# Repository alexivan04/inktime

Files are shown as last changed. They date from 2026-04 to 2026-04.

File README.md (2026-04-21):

# InkTime – Open Source Smartwatch Hardware Project

## Overview
InkTime is an open-source, low-cost smartwatch hardware platform designed for mass production.  
This repository contains the complete hardware, manufacturing, and mechanical design files for the device.

The project includes:
- electronic schematic and PCB layout
- manufacturing outputs (Gerber, BOM, Pick & Place)
- complete 3D mechanical assembly
- documentation and design decisions
- validation and review updates

## Repository Structure

```text
InkTime/
│
├── Hardware/
│   ├── inktime.sch
│   ├── inktime.brd
│   └── schematic.pdf
│
├── Manufacturing/
│   ├── gerbers.zip
│   ├── bom.csv
│   └── pick_and_place.csv
│
├── Mechanical/
│   ├── inktime_assembly.step
│   └── inktime_assembly.f3d
│
├── Images/
│   ├── pcb_top.png
│   ├── pcb_bottom.png
│   ├── render_front.png
│   └── exploded_view.png
│
├── LICENSE
└── README.md
````

---

## Block Diagram

```text
Battery
   │
   ▼
Power Management (charger + regulation)
   │
   ▼
nRF52840 Microcontroller
   ├── IMU Sensor (I2C / SPI)
   ├── E-paper Display (SPI)
   ├── Buttons (GPIO)
   ├── USB-C Interface
   ├── Vibration Motor / Shaker
   └── Debug / Test Pads
```

---

## Hardware Architecture

The smartwatch is built around the **nRF52840** microcontroller, selected for:

* low power consumption
* integrated BLE support
* sufficient GPIO availability
* embedded ARM Cortex-M4 core

### Main Modules

* **Microcontroller:** nRF52840
* **Display:** e-paper display connected via SPI
* **Motion Sensor:** IMU connected via I2C/SPI
* **Power Supply:** Li-Po battery with charging IC and voltage regulation
* **User Input:** 3 push buttons
* **Feedback:** vibration motor (shaker)
* **Communication:** USB-C + BLE
* **Programming/Test:** dedicated test pads

---

## PCB Design Notes

### Stack-up

* **4-layer PCB**
* components placed **TOP layer only**
* routing on both TOP and BOTTOM
* GND planes on 1 and 3 layers

### Routing Rules

* power traces: **0.30 mm**
* signal traces: **minimum 0.15 mm**
* no right-angle routing
* minimized vias on power lines
* decoupling capacitors placed near IC supply pins

### RF Requirements

* antenna positioned at PCB edge
* no copper under antenna
* no signal traces below antenna
* board cutout included below antenna region

---

## Mechanical Integration

The PCB is designed to fit inside the provided smartwatch enclosure.

## Design Decisions / Notes

* accepted minor dimension warnings for button and USB alignment per project instructions
* battery connected directly to test pads to save internal volume
* all decoupling capacitors placed as close as possible to supply pins
* RF section isolated with stitched ground vias

---

## License

This project is released under the **Apache 2.0 License**.

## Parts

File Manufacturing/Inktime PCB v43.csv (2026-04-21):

Qty | Value | Device | Package | Parts | Description | ARROW_PART_NUMBER | ARROW_PRICE-STOCK | AVAILABILITY | CHECK_PRICES | COPYRIGHT | DESCRIPTION | DIGI-KEY_PART_NUMBER_1 | DIGI-KEY_PART_NUMBER_2 | DIGI-KEY_PART_NUMBER_3 | HEIGHT | JLCPCB | MANUFACTURER_NAME | MANUFACTURER_PART_NUMBER | MF | MFR_NAME | MOUSER_PART_NUMBER | MOUSER_PRICE-STOCK | MP | PACKAGE | POPULARITY | PRICE | PROD_ID | PURCHASE-URL | SNAPEDA_LINK | SPICEMODEL | SPICEPREFIX | TP_SIGNAL_NAME | VALUE
1 |  | ESP32_C6_LIBRARY_7_JUMPER_SJ | ESP32_C6_LIBRARY_7_JUMPER_SJ | SJ1 | SMD solder JUMPER |  |  |  |  |  |  |  |  |  |  |  |  |  |  |  |  |  |  |  | 3
1 |  | NORDIC_NRF_2_INDUCTOR_0402_L | NORDIC_NRF_2_RESC0402_L | U$5 | Generic chip inductor
3 | 0 | ERA-1AEB3401C_CPF0201D7K68C1 | ERA-1AEB3401C_0201 | R6, R7, R15 | 7.68k 0201 Thin Film Surface Mount Fixed Resistor +/-0.5% 0.031W CPF0201D7K68C1
6 | 0.1u | GRM011R60J152KE01L_2_GRM011R60J152KE01L | GRM011R60J152KE01L_2_CAPC0201X13N | C4, C5, C7, C8, C9, C37 | Check availability |  |  | In Stock | https://www.snapeda.com/parts/GRM011R60J152KE01L/Murata/view-part/?ref=eda |  | SMD Capacitor X5R(EIA) with Capacitance: 1500pF Tol. 10%. Rated Voltage: 6.3Vdc |  |  |  |  |  |  |  | Murata |  |  |  | GRM011R60J152KE01L | 0201 Murata |  | None |  |  | https://www.snapeda.com/parts/GRM011R60J152KE01L/Murata/view-part/?ref=snap
1 | 0.1u/50V | NORDIC_NRF_3_CAPACITOR_0201_L | NORDIC_NRF_3_RESC0201_L | C48 | Generic chip capacitor
1 | 0.47 | ERA-1AEB3401C_CPF0201D7K68C1 | ERA-1AEB3401C_0201 | R2 | 7.68k 0201 Thin Film Surface Mount Fixed Resistor +/-0.5% 0.031W CPF0201D7K68C1
1 | 1.0u | ESP32_C6_LIBRARY_1_ESP32_WROVER_EAGLE-LTSPICE_CC0402 | ESP32_C6_LIBRARY_1_ESP32_WROVER_EAGLE-LTSPICE_C0402 | C14 | CAPACITOR, European symbol |  |  |  |  |  |  |  |  |  |  |  |  |  |  |  |  |  |  |  |  |  |  |  |  | NONE | C
5 | 100n | NORDIC_NRF_3_CAPACITOR_0201_L | NORDIC_NRF_3_RESC0201_L | C3, C22, C26, C30, C33 | Generic chip capacitor
1 | 100p | NORDIC_NRF_3_CAPACITOR_0201_L | NORDIC_NRF_3_RESC0201_L | C23 | Generic chip capacitor
5 | 10K | ERA-1AEB3401C_CPF0201D7K68C1 | ERA-1AEB3401C_0201 | R1, R5, R12, R13, R14 | 7.68k 0201 Thin Film Surface Mount Fixed Resistor +/-0.5% 0.031W CPF0201D7K68C1
2 | 10u | ESP32_C6_LIBRARY_1_ESP32_WROVER_EAGLE-LTSPICE_CC0402 | ESP32_C6_LIBRARY_1_ESP32_WROVER_EAGLE-LTSPICE_C0402 | C11, C17 | CAPACITOR, European symbol |  |  |  |  |  |  |  |  |  |  |  |  |  |  |  |  |  |  |  |  |  |  |  |  | NONE | C
1 | 10u | NORDIC_NRF_2_INDUCTOR_0402_L | NORDIC_NRF_2_RESC0402_L | U$8 | Generic chip inductor
2 | 12p | NORDIC_NRF_3_CAPACITOR_0201_L | NORDIC_NRF_3_RESC0201_L | C27, C28 | Generic chip capacitor
1 | 15n | NORDIC_NRF_2_INDUCTOR_0402_L | NORDIC_NRF_2_RESC0402_L | U$4 | Generic chip inductor
4 | 1u | GRM011R60J152KE01L_2_GRM011R60J152KE01L | GRM011R60J152KE01L_2_CAPC0201X13N | C1, C2, C6, C10 | Check availability |  |  | In Stock | https://www.snapeda.com/parts/GRM011R60J152KE01L/Murata/view-part/?ref=eda |  | SMD Capacitor X5R(EIA) with Capacitance: 1500pF Tol. 10%. Rated Voltage: 6.3Vdc |  |  |  |  |  |  |  | Murata |  |  |  | GRM011R60J152KE01L | 0201 Murata |  | None |  |  | https://www.snapeda.com/parts/GRM011R60J152KE01L/Murata/view-part/?ref=snap
10 | 1u/50V | NORDIC_NRF_3_CAPACITOR_0201_L | NORDIC_NRF_3_RESC0201_L | C38, C39, C40, C41, C42, C43, C44, C45, C46, C47 | Generic chip capacitor
2 | 2.2 | ERA-1AEB3401C_CPF0201D7K68C1 | ERA-1AEB3401C_0201 | R3, R4 | 7.68k 0201 Thin Film Surface Mount Fixed Resistor +/-0.5% 0.031W CPF0201D7K68C1
3 | 2025-10-22_07-23-44_LIBRARY_EVP-AKE31ASW_EVP-AKE31A_PAN | 2025-10-22_07-23-44_LIBRARY_EVP-AKE31ASW_EVP-AKE31A_PAN | 2025-10-22_07-23-44_LIBRARY_SW_EVP-AKE31A_PAN | SW1, SW2, SW3 |  |  |  |  |  | Copyright (C) 2025 Ultra Librarian. All rights reserved. |  | P123437TR-ND | P123437CT-ND | P123437DKR-ND |  |  | Panasonic | EVP-AKE31A
1 | 20V/4.2A/52mO/1.4W | ESP32_C6_LIBRARY_4_ESP32_WROVER_SPARKFUN-DISCRETESEMI_MOSFET_PCH-DMG2305UX-7 | ESP32_C6_LIBRARY_4_ESP32_C6_LIBRARY_4_ESP32_C6_LIBRARY_4_ESP32_C6_LIBRARY_4_ESP32_WROVER_SPARKFUN-DISCRETESEMI_SOT23-3 | Q2 | P-channel MOSFETs |  |  |  |  |  |  |  |  |  |  |  |  |  |  |  |  |  |  |  |  |  | TRAN-14388 |  |  |  |  |  | 20V/4.2A/52mO/1.4W
2 | 22u | ESP32_C6_LIBRARY_1_ESP32_WROVER_EAGLE-LTSPICE_CC0402 | ESP32_C6_LIBRARY_1_ESP32_WROVER_EAGLE-LTSPICE_C0402 | C12, C13 | CAPACITOR, European symbol |  |  |  |  |  |  |  |  |  |  |  |  |  |  |  |  |  |  |  |  |  |  |  |  | NONE | C
1 | 2450AT18B100E_2450AT18B100E | 2450AT18B100E_2450AT18B100E | 2450AT18B100E_ANTC3216X140N | ANT1 | Antennas 2.45GHz ANTENNA | 2450AT18B100E | https://www.arrow.com/en/products/2450at18b100e/johanson-dielectrics?utm_currency=USD&region=nac |  |  |  | Antennas 2.45GHz ANTENNA |  |  |  | 1.4mm |  | JOHANSON TECHNOLOGY | 2450AT18B100E |  |  | 609-2450AT18B100E | https://www.mouser.co.uk/ProductDetail/Johanson-Technology/2450AT18B100E?qs=yCnrNFeXz%252Bh5MFsFIXGZGA%3D%3D
1 | 32.768kHz | NORDIC_NRF_1_XTAL_32KHZ | NORDIC_NRF_1_XTAL_3215_N | X1
1 | 32MHz | NORDIC_NRF_XTAL_32MHZ | NORDIC_NRF_BT-XTAL_2016_N | U$22
2 | 3K3 | ERA-1AEB3401C_CPF0201D7K68C1 | ERA-1AEB3401C_0201 | R10, R11 | 7.68k 0201 Thin Film Surface Mount Fixed Resistor +/-0.5% 0.031W CPF0201D7K68C1
1 | 4.7u | ESP32_C6_LIBRARY_1_ESP32_WROVER_EAGLE-LTSPICE_CC0402 | ESP32_C6_LIBRARY_1_ESP32_WROVER_EAGLE-LTSPICE_C0402 | C15 | CAPACITOR, European symbol |  |  |  |  |  |  |  |  |  |  |  |  |  |  |  |  |  |  |  |  |  |  |  |  | NONE | C
6 | 4.7u | NORDIC_NRF_3_CAPACITOR_0201_L | NORDIC_NRF_3_RESC0201_L | C18, C19, C34, C35, C36, U$20 | Generic chip capacitor
1 | 4.7u/25V | ESP32_C6_LIBRARY_1_ESP32_WROVER_EAGLE-LTSPICE_CC0402 | ESP32_C6_LIBRARY_1_ESP32_WROVER_EAGLE-LTSPICE_C0402 | C16 | CAPACITOR, European symbol |  |  |  |  |  |  |  |  |  |  |  |  |  |  |  |  |  |  |  |  |  |  |  |  | NONE | C
2 | 47n | NORDIC_NRF_3_CAPACITOR_0201_L | NORDIC_NRF_3_RESC0201_L | C20, C49 | Generic chip capacitor
1 | 503480-2400_503480-2400 | 503480-2400_503480-2400 | 503480-2400_5034802400 | J3 | FFC & FPC Connectors 0.5mm FPC RA SMT Dual Contact 24Ckt |  |  |  |  |  | FFC & FPC Connectors 0.5mm FPC RA SMT Dual Contact 24Ckt |  |  |  | 1.87mm |  | Molex | 503480-2400 |  |  | 538-503480-2400 | https://www.mouser.co.uk/ProductDetail/Molex/503480-2400?qs=OAhjpuo3Vu7efIoxFh9AOw%3D%3D
2 | 5K1 | ERA-1AEB3401C_CPF0201D7K68C1 | ERA-1AEB3401C_0201 | R8, R9 | 7.68k 0201 Thin Film Surface Mount Fixed Resistor +/-0.5% 0.031W CPF0201D7K68C1
1 | 68u | ESP32_C6_LIBRARY_2_744043680IND_4828-WE-TPC_WRE | ESP32_C6_LIBRARY_2_IND_4828-WE-TPC_WRE | L4 |  |  |  |  |  | Copyright (C) 2024 Ultra Librarian. All rights reserved. |  |  |  |  |  |  |  | 744043680 |  | Wurth Electronics
1 | 820p | NORDIC_NRF_3_CAPACITOR_0201_L | NORDIC_NRF_3_RESC0201_L | C25 | Generic chip capacitor
1 | BMA423_BMA423 | BMA423_BMA423 | BMA423_BMA423 | IC4 | Accelerometers Triaxial low-g 12bit Acceleration Sensor | BMA423 | https://www.arrow.com/en/products/bma423/bosch |  |  |  | Accelerometers Triaxial low-g 12bit Acceleration Sensor |  |  |  | 1mm |  | BOSCH | BMA423 |  |  | 262-BMA423 | https://www.mouser.co.uk/ProductDetail/Bosch-Sensortec/BMA423?qs=HXFqYaX1Q2xC%252BSgeGoX3mg%3D%3D
1 | BQ25180YBGR_BQ25180YBGR | BQ25180YBGR_BQ25180YBGR | BQ25180YBGR_BGA8C40P2X4_100X155X50 | IC1 | Charger IC Lithium Ion/Polymer, Lithium Iron Phosphate 8-DSBGA (1.6x1.1) | BQ25180YBGR | https://www.arrow.com/en/products/bq25180ybgr/texas-instruments?utm_currency=USD&region=nac |  |  |  | Charger IC Lithium Ion/Polymer | Lithium Iron Phosphate 8-DSBGA (1.6x1.1) |  |  |  | 0.5mm |  | Texas Instruments | BQ25180YBGR |  |  | 595-BQ25180YBGR | https://www.mouser.co.uk/ProductDetail/Texas-Instruments/BQ25180YBGR?qs=doiCPypUmgEWjAK%252BJAX6Tw%3D%3D
1 | DRV2605YZFR_DRV2605YZFR | DRV2605YZFR_DRV2605YZFR | DRV2605YZFR_BGA9C50P3X3_144X144X62 | IC3 | Haptic Driver for ERM/LRA with Built-In Library and Smart Loop Architecture | DRV2605YZFR | https://www.arrow.com/en/products/drv2605yzfr/texas-instruments?region=nac |  |  |  | Haptic Driver for ERM/LRA with Built-In Library and Smart Loop Architecture |  |  |  | 0.625mm |  | Texas Instruments | DRV2605YZFR
1 | ESP32_C6_LIBRARY_3_USBLC6-2SC6Y | ESP32_C6_LIBRARY_3_USBLC6-2SC6Y | ESP32_C6_LIBRARY_3_SOT95P280X145-6N | D4 | Low Cap. ESD Protection Auto SOT-23-6 STMicroelectronics USBLC6-2SC6Y, Dual Uni-Directional TVS Diode Array, 6-Pin SOT-23 |  |  | In Stock | https://www.snapeda.com/parts/USBLC6-2SC6Y/STMicroelectronics/view-part/?ref=eda |  | 17V Clamp 5A (8/20µs) Ipp Tvs Diode Surface Mount SOT-23-6 |  |  |  |  |  |  |  | STMicroelectronics |  |  |  | USBLC6-2SC6Y | SOT-23-6 STMicroelectronics |  | None |  |  | https://www.snapeda.com/parts/USBLC6-2SC6Y/STMicroelectronics/view-part/?ref=snap
3 | ESP32_C6_LIBRARY_5_MBR0530 | ESP32_C6_LIBRARY_5_MBR0530 | ESP32_C6_LIBRARY_5_SOD3716X135N | D1, D2, D3 | ON SEMICONDUCTOR - MBR0530 - DIODE, SCHOTTKY, 0.5A, 30V, SOD-123 |  |  | In Stock | https://www.snapeda.com/parts/MBR0530/Onsemi/view-part/?ref=eda |  | Diode Schottky 30 V 500mA Surface Mount SOD-123 |  |  |  |  |  |  |  | ON Semiconductor |  |  |  | MBR0530 | SOD-123-2 ON Semiconductor |  | None |  | https://www.snapeda.com/api/url_track_click_mouser/?unipart_id=179458&manufacturer=ON Semiconductor&part_name=MBR0530&search_term=None | https://www.snapeda.com/parts/MBR0530/Onsemi/view-part/?ref=snap
1 | ESP32_C6_LIBRARY_6_SI1308EDL-T1-GE3 | ESP32_C6_LIBRARY_6_SI1308EDL-T1-GE3 | ESP32_C6_LIBRARY_6_SOT65P210X110-3N | Q1 | MOSFET N-Ch 30V 1.5A TrenchFET SC70 Vishay Si1308EDL-T1-GE3 N-channel MOSFET Transistor, 1.5 A, 30 V, 3-Pin SC-70 |  |  | In Stock | https://www.snapeda.com/parts/SI1308EDL-T1-GE3/Vishay+Siliconix/view-part/?ref=eda |  | Si1308EDL-T1-GE3 N-channel MOSFET Transistor | 1.5 A | 30 V | 3-Pin SC-70 | Siliconix / Vishay SI1308EDL-T1-GE3 |  |  |  |  |  |  |  | Vishay Siliconix |  |  |  | SI1308EDL-T1-GE3 | SOT-323 Vishay Semiconductor |  | None |  | https://www.snapeda.com/api/url_track_click_mouser/?unipart_id=274603&manufacturer=Vishay Siliconix&part_name=SI1308EDL-T1-GE3&search_term=None | https://www.snapeda.com/parts/SI1308EDL-T1-GE3/Vishay+Siliconix/view-part/?ref=snap
1 | ESP32_C6_LIBRARY_MAX17048G+T10 | ESP32_C6_LIBRARY_MAX17048G+T10 | ESP32_C6_LIBRARY_SON50P200X200X80-9N | U1 | Check availability |  |  | In Stock | https://www.snapeda.com/parts/MAX17048G+T10/Analog+Devices/view-part/?ref=eda |  | 3µA 1-Cell/2-Cell Fuel Gauge with ModelGauge |  |  |  |  |  |  |  | Analog Devices |  |  |  | MAX17048G+T10 | TDFN-8 Maxim |  | None |  | https://www.snapeda.com/api/url_track_click_mouser/?unipart_id=329239&manufacturer=Analog Devices&part_name=MAX17048G+T10&search_term=None | https://www.snapeda.com/parts/MAX17048G+T10/Analog+Devices/view-part/?ref=snap
13 | HECTOR_WATCH_1_TPTP20R | HECTOR_WATCH_1_TPTP20R | HECTOR_WATCH_1_TP20R | TP1, TP2, TP3, TP4, TP5, TP6, TP7, TP8, TP9, TP10, TP11, TP12, TP13 | Test pad |  |  |  |  |  |  |  |  |  |  |  |  |  |  |  |  |  |  |  | 2
1 | KH-TYPE-C-16P_KH-TYPE-C-16P | KH-TYPE-C-16P_KH-TYPE-C-16P | KH-TYPE-C-16P_KINGHELM_KH-TYPE-C-16P | J1 | Check availability |  |  | Not in stock | https://www.snapeda.com/parts/KH-TYPE-C-16P/Kinghelm/view-part/?ref=eda |  |  |  |  |  |  |  |  |  | kinghelm |  |  |  | KH-TYPE-C-16P | None |  | None |  |  | https://www.snapeda.com/parts/KH-TYPE-C-16P/Kinghelm/view-part/?ref=snap
1 | MLP2016SR47MT0S1_FTC252012SR47MBCA | MLP2016SR47MT0S1_FTC252012SR47MBCA | MLP2016SR47MT0S1_INDC2016X100N | L2 | SMD / SMT Inductors (Coils), L=0.47?H, L x W x T : |  |  |  |  |  | SMD / SMT Inductors (Coils) | L=0.47?H | L x W x T : |  |  |  | 1mm | https://jlcpcb.com/partdetail/6763488-FTC252012SR47MBCA/C5832368 | TDK | FTC252012SR47MBCA
5 | N.C | NORDIC_NRF_3_CAPACITOR_0201_L | NORDIC_NRF_3_RESC0201_L | C21, C24, C29, C31, C32 | Generic chip capacitor
1 | NORDIC_NRF_4_NRF52840_QF | NORDIC_NRF_4_NRF52840_QF | NORDIC_NRF_4_AQFN50P700X700X85_HS-74N | U$31 | nRF52840
1 | RT6160AWSC_RT6160AWSC | RT6160AWSC_RT6160AWSC | RT6160AWSC_BGA15C40P3X5_140X230X60 | IC2 | Buck-Boost Regulator Positive Output Step-Up/Step-Down I2C DC-DC Controller IC 15-WL-CSP (BSC) (1.4x2.3) |  |  |  |  |  | Buck-Boost Regulator Positive Output Step-Up/Step-Down I2C DC-DC Controller IC 15-WL-CSP (BSC) (1.4x2.3) |  |  |  | 0.6mm |  | RICHTEK | RT6160AWSC |  |  | 835-RT6160AWSC | https://www.mouser.co.uk/ProductDetail/Richtek/RT6160AWSC?qs=amGC7iS6iy%2FLd9PSoixZXQ%3D%3D
1 | TC2030-IDC_TC2030-IDC | TC2030-IDC_TC2030-IDC | TC2030-IDC_TC2030IDC | J2 | CABLE ADAPTER 6 POS |  |  |  |  |  | CABLE ADAPTER 6 POS |  |  |  | 19mm |  | Tag Connect | TC2030-IDC

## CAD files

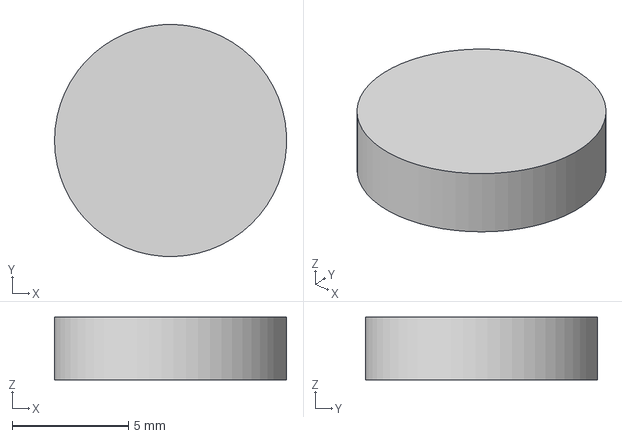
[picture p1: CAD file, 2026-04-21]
Mechanical/Vibrate_3dModel.step
9.99 x 10.00 x 2.70 mm

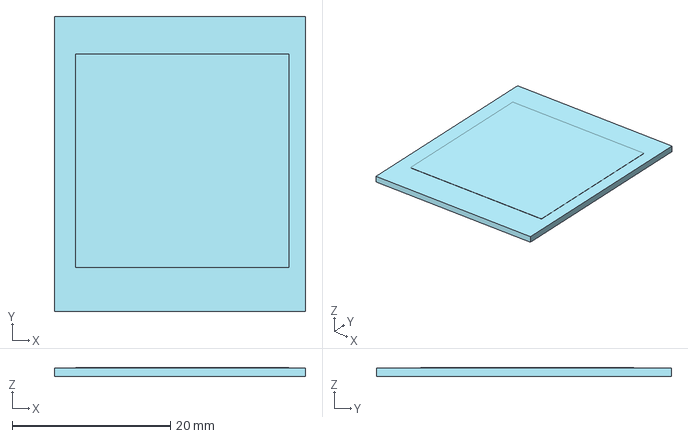
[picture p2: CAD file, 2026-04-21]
Mechanical/Display_3dModel.step
31.8 x 37.3 x 1.10 mm

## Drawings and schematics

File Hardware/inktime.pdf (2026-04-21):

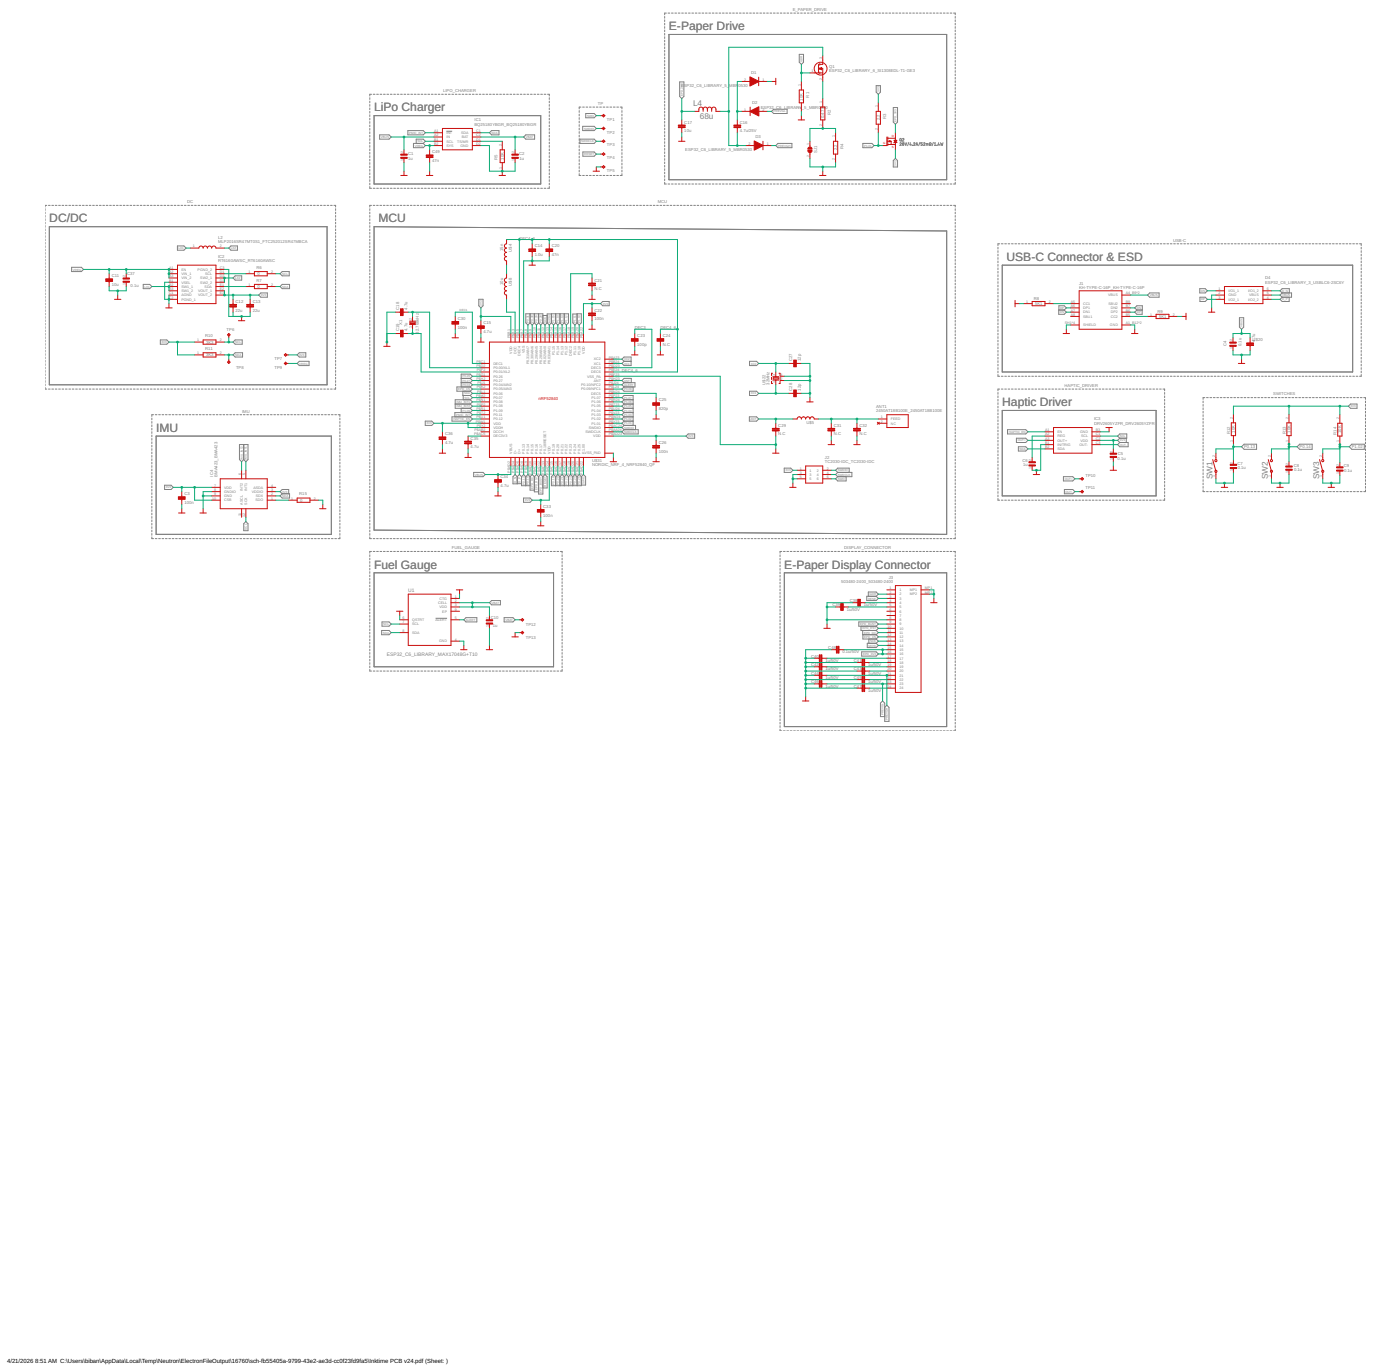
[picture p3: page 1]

1u/50V C41 | 18
C42 | | 1u/50V 19
1u/50V C43 | 20
C44 | | 1u/50V 21
1u/50V C45 | | 22
C46 | | 1u/50V | 23
1u/50V C47 | | | 24

4/21/2026 8:51 AM C:\Users\biban\AppData\Local\Temp\Neutron\ElectronFileOutput\16760\sch-fb55405a-9799-43e2-ae3d-cc0f23fd9fa5\Inktime PCB v24.pdf (Sheet: )

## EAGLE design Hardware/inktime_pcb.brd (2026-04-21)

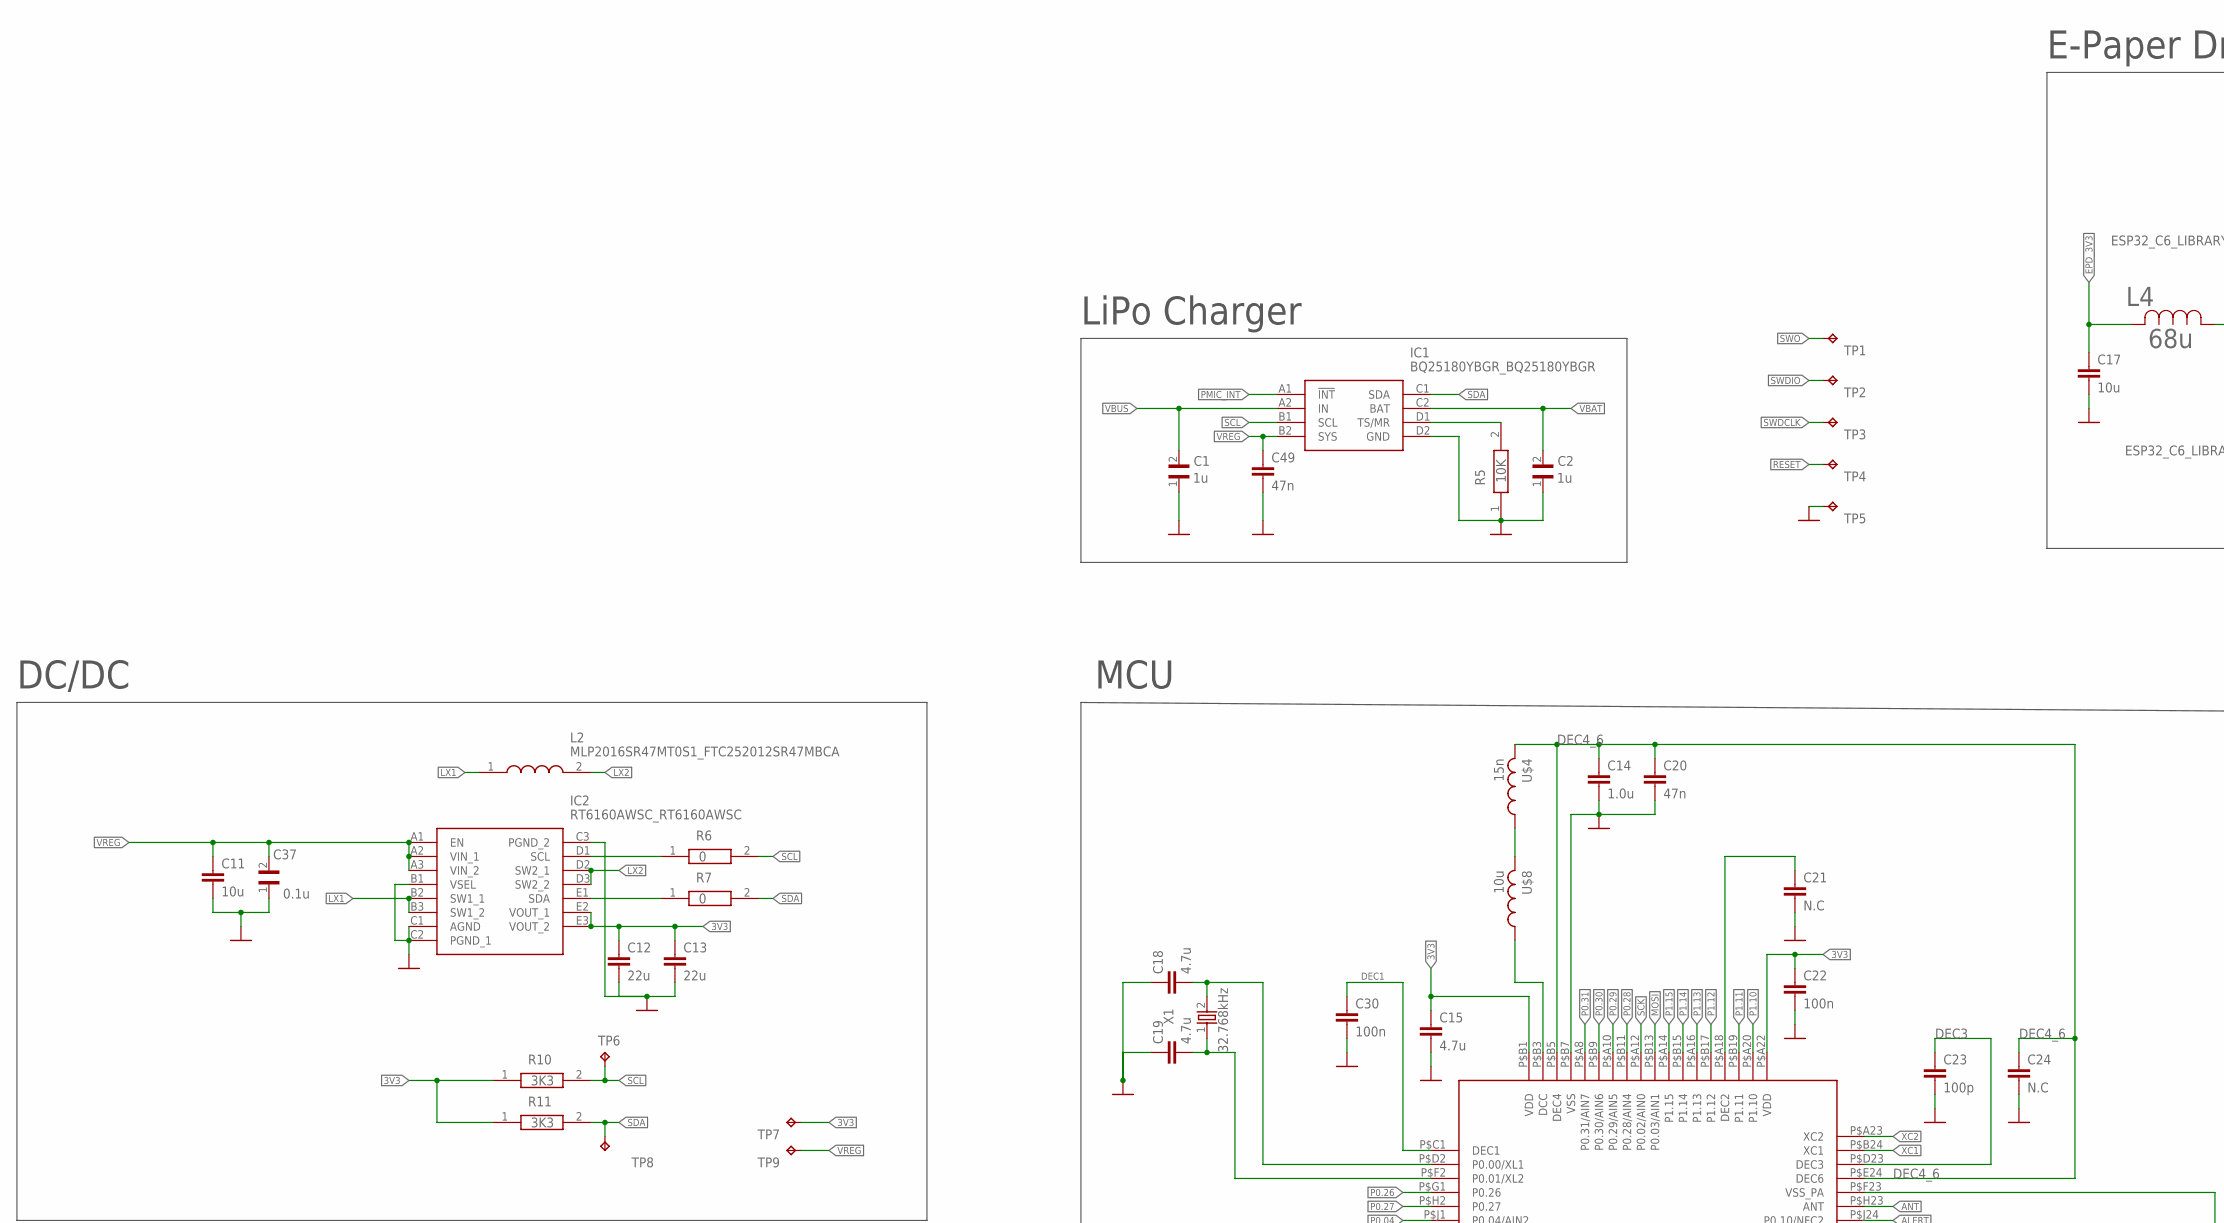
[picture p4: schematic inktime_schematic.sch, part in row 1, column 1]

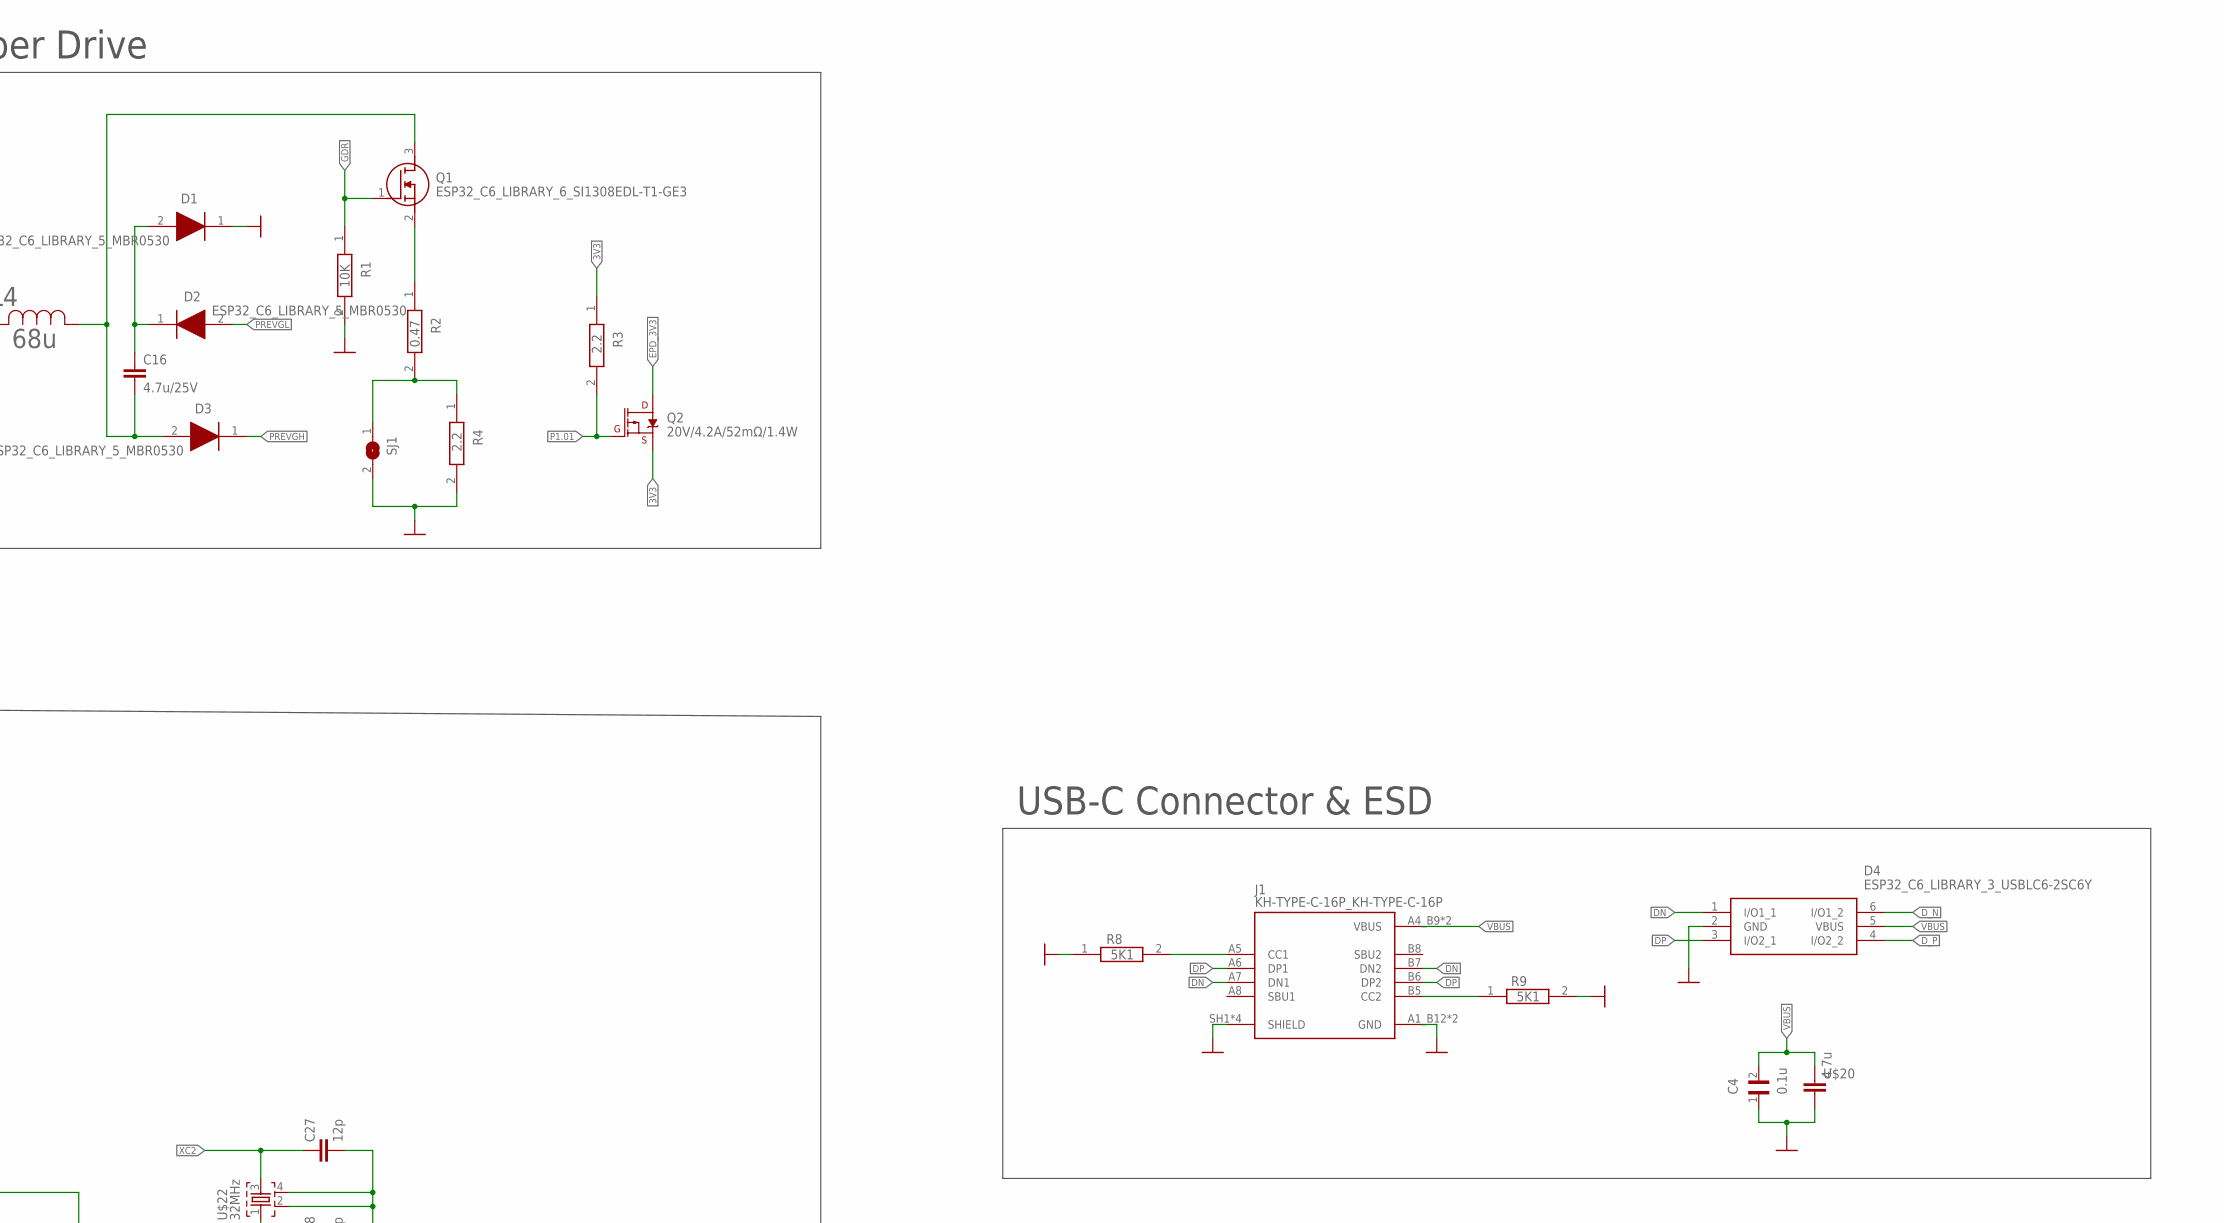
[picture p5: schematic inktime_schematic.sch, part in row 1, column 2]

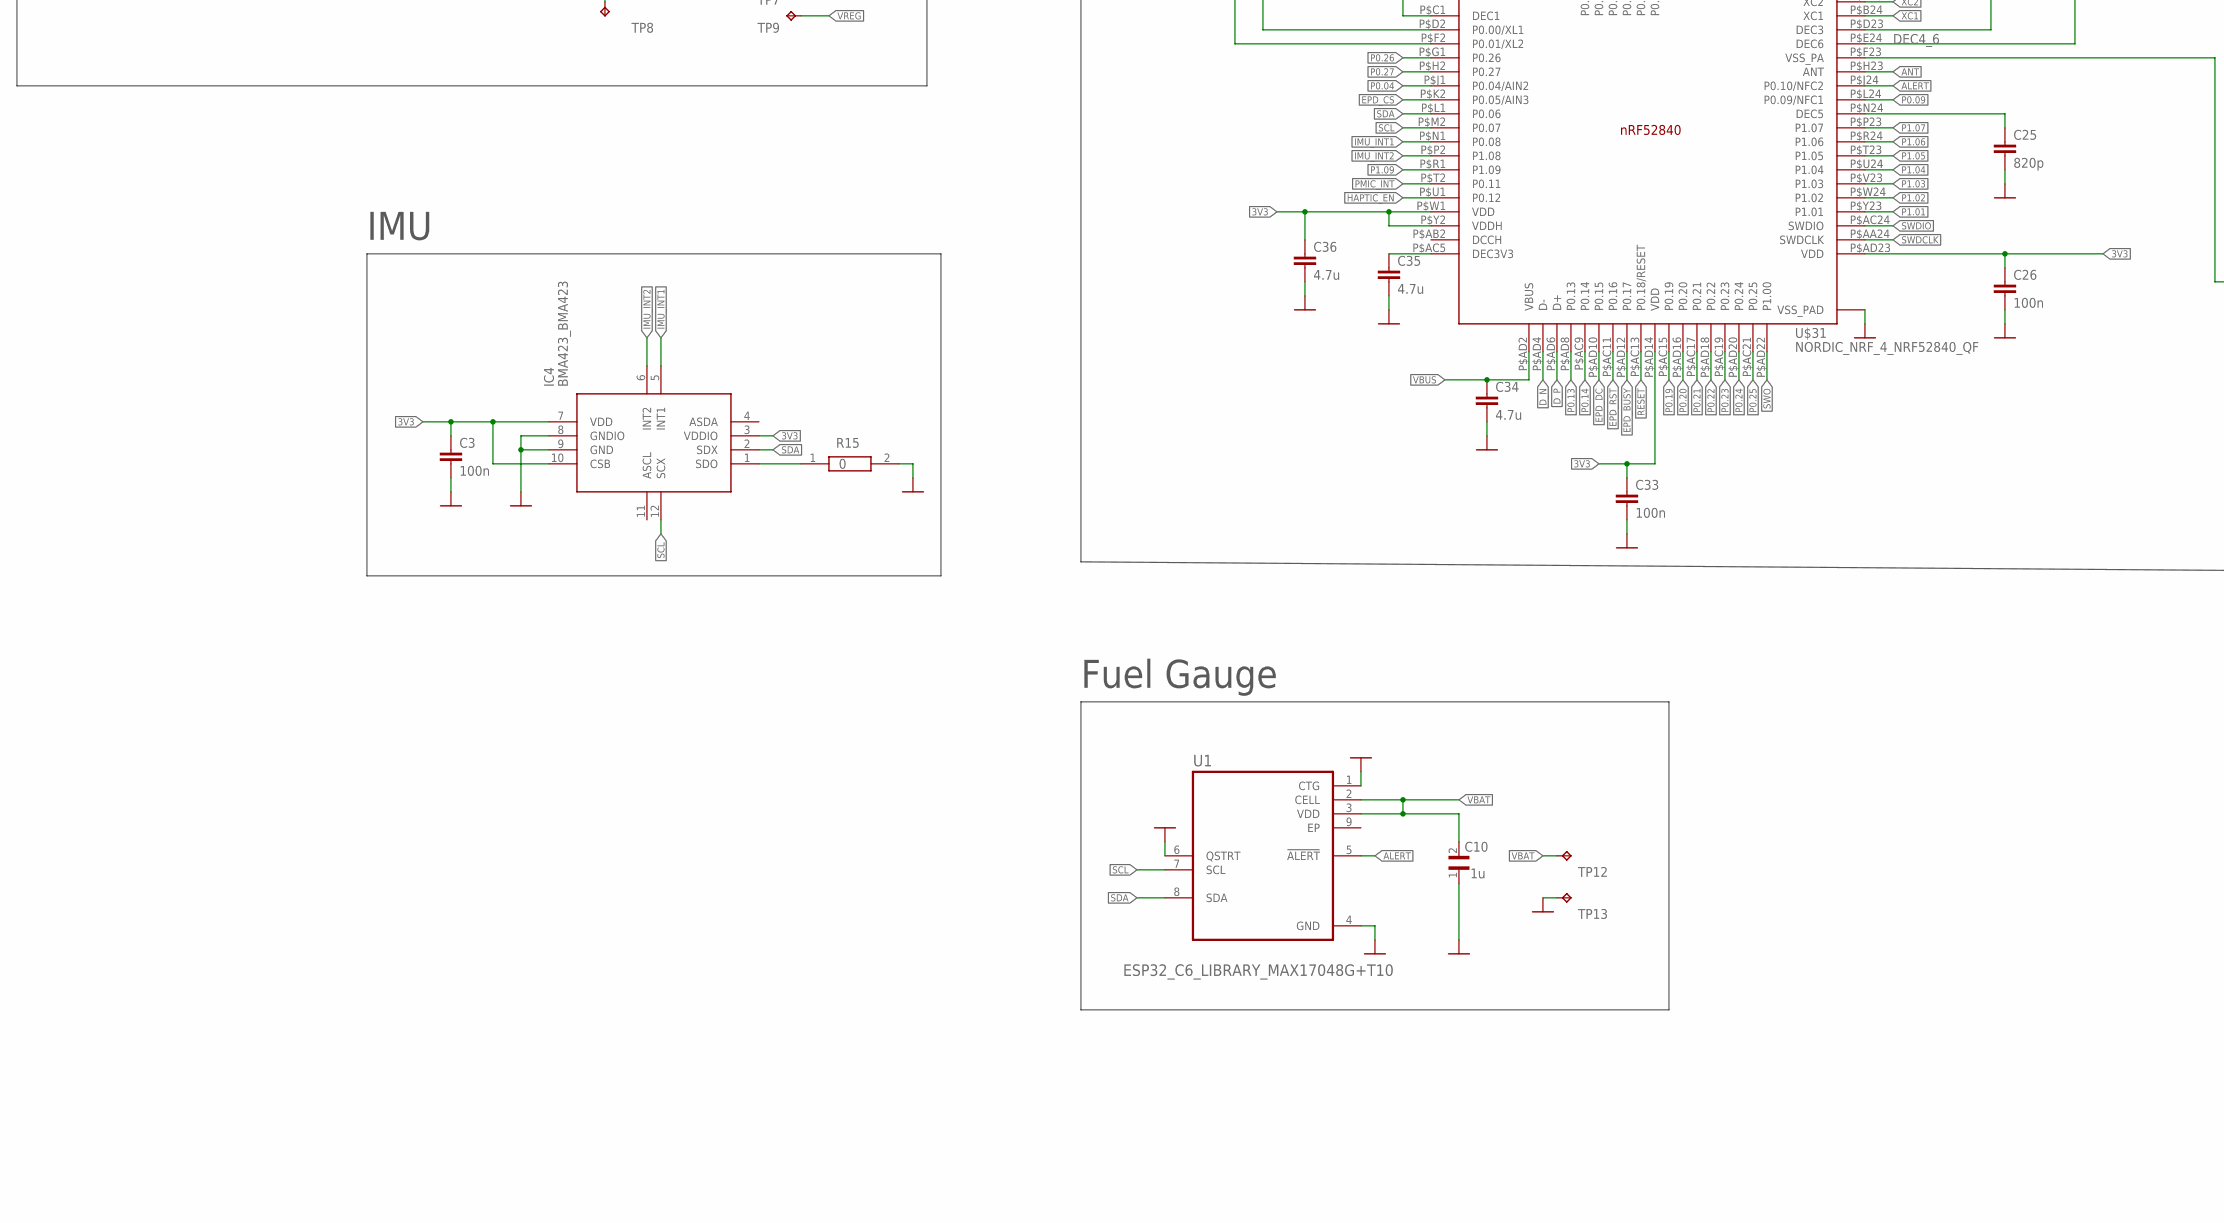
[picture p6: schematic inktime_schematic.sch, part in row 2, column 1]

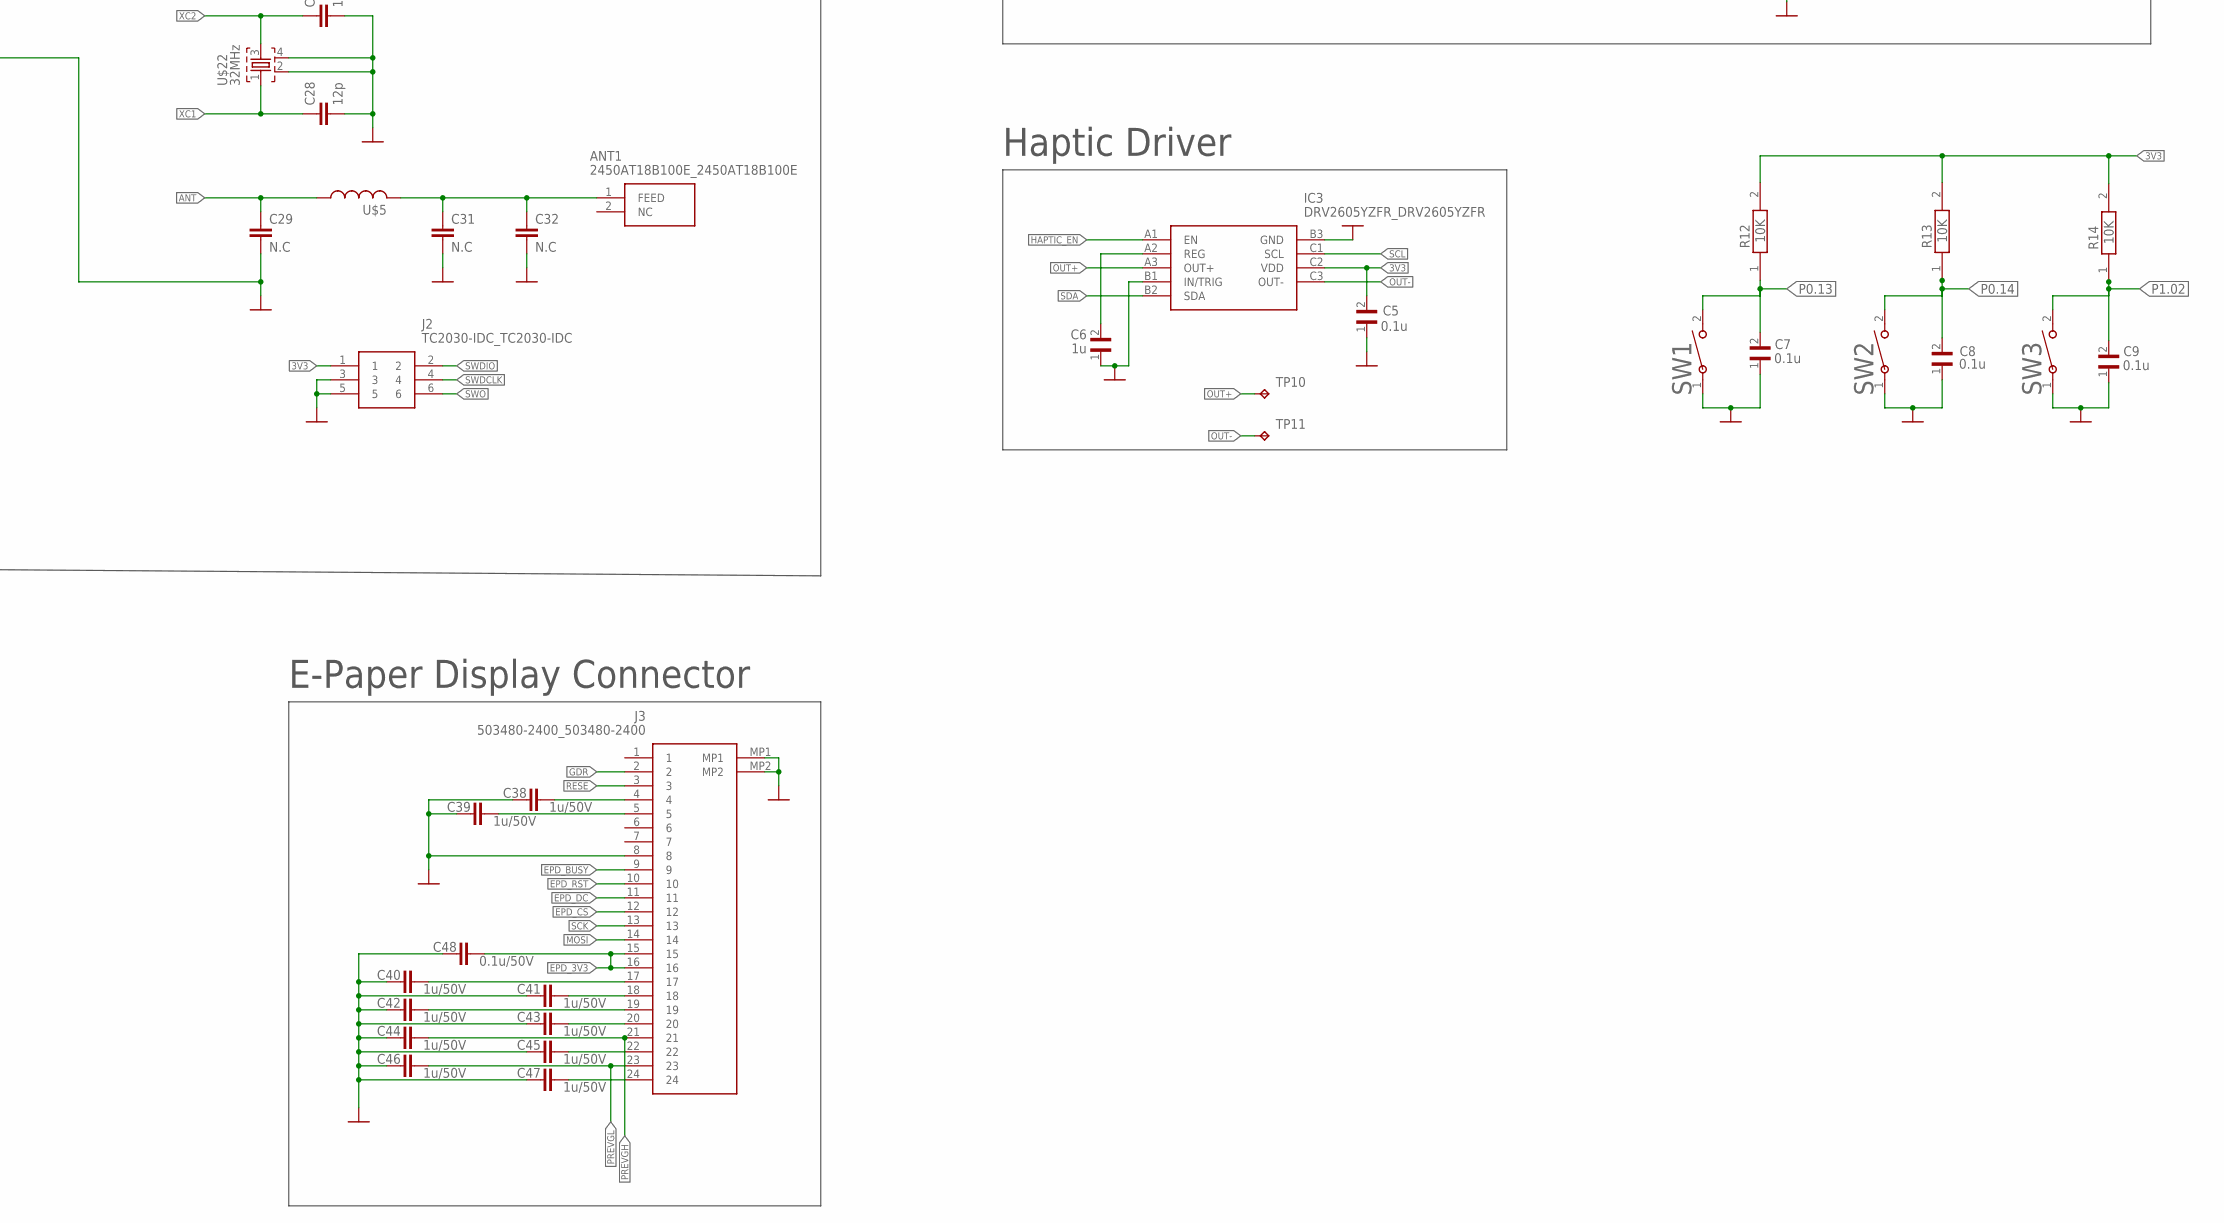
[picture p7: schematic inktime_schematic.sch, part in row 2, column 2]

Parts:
ANT1: 2450AT18B100E_2450AT18B100E; 2450AT18B100E_ANTC3216X140N
C1, C2, C6, C10: 1u; GRM011R60J152KE01L_2_CAPC0201X13N
C3, C22, C26, C30, C33: 100n; NORDIC_NRF_3_RESC0201_L
C4, C5, C7, C8, C9, C37: 0.1u; GRM011R60J152KE01L_2_CAPC0201X13N
C11, C17: 10u; ESP32_C6_LIBRARY_1_ESP32_WROVER_EAGLE-LTSPICE_C0402
C12, C13: 22u; ESP32_C6_LIBRARY_1_ESP32_WROVER_EAGLE-LTSPICE_C0402
C14: 1.0u; ESP32_C6_LIBRARY_1_ESP32_WROVER_EAGLE-LTSPICE_C0402
C15: 4.7u; ESP32_C6_LIBRARY_1_ESP32_WROVER_EAGLE-LTSPICE_C0402
C16: 4.7u/25V; ESP32_C6_LIBRARY_1_ESP32_WROVER_EAGLE-LTSPICE_C0402
C18, C19, C34, C35, C36: 4.7u; NORDIC_NRF_3_RESC0201_L
C20, C49: 47n; NORDIC_NRF_3_RESC0201_L
C21, C24, C29, C31, C32: N.C; NORDIC_NRF_3_RESC0201_L
C23: 100p; NORDIC_NRF_3_RESC0201_L
C25: 820p; NORDIC_NRF_3_RESC0201_L
C27, C28: 12p; NORDIC_NRF_3_RESC0201_L
C38, C39, C40, C41, C42, C43, C44, C45, C46, C47: 1u/50V; NORDIC_NRF_3_RESC0201_L
C48: 0.1u/50V; NORDIC_NRF_3_RESC0201_L
D1, D2, D3: ESP32_C6_LIBRARY_5_MBR0530; ESP32_C6_LIBRARY_5_SOD3716X135N
D4: ESP32_C6_LIBRARY_3_USBLC6-2SC6Y; ESP32_C6_LIBRARY_3_SOT95P280X145-6N
IC1: BQ25180YBGR_BQ25180YBGR; BQ25180YBGR_BGA8C40P2X4_100X155X50
IC2: RT6160AWSC_RT6160AWSC; RT6160AWSC_BGA15C40P3X5_140X230X60
IC3: DRV2605YZFR_DRV2605YZFR; DRV2605YZFR_BGA9C50P3X3_144X144X62
IC4: BMA423_BMA423
J1: KH-TYPE-C-16P_KH-TYPE-C-16P; KH-TYPE-C-16P_KINGHELM_KH-TYPE-C-16P
J2: TC2030-IDC_TC2030-IDC; TC2030-IDC_TC2030IDC
J3: 503480-2400_503480-2400; 503480-2400_5034802400
L2: MLP2016SR47MT0S1_FTC252012SR47MBCA; MLP2016SR47MT0S1_INDC2016X100N
L4: 68u; ESP32_C6_LIBRARY_2_IND_4828-WE-TPC_WRE
Q1: ESP32_C6_LIBRARY_6_SI1308EDL-T1-GE3; ESP32_C6_LIBRARY_6_SOT65P210X110-3N
Q2: 20V/4.2A/52mΩ/1.4W; ESP32_C6_LIBRARY_4_ESP32_C6_LIBRARY_4_ESP32_C6_LIBRARY_4_ES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
R1, R5, R12, R13, R14: 10K; ERA-1AEB3401C_0201
R2: 0.47; ERA-1AEB3401C_0201
R3, R4: 2.2; ERA-1AEB3401C_0201
R6, R7, R15: 0; ERA-1AEB3401C_0201
R8, R9: 5K1; ERA-1AEB3401C_0201
R10, R11: 3K3; ERA-1AEB3401C_0201
SJ1: ESP32_C6_LIBRARY_7_JUMPER_SJ
SW1, SW2, SW3: 2025-10-22_07-23-44_LIBRARY_EVP-AKE31ASW_EVP-AKE3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; 2025-10-22_07-23-44_LIBRARY_SW_EVP-AKE31A_PAN
TP1, TP2, TP3, TP4, TP5, TP6, TP7, TP8, TP9, TP10, TP11, TP12, TP13: HECTOR_WATCH_1_TPTP20R; HECTOR_WATCH_1_TP20R
U1: ESP32_C6_LIBRARY_MAX17048G+T10; ESP32_C6_LIBRARY_SON50P200X200X80-9N
U$4: 15n; NORDIC_NRF_2_RESC0402_L
U$5: NORDIC_NRF_2_INDUCTOR_0402_L; NORDIC_NRF_2_RESC0402_L
U$8: 10u; NORDIC_NRF_2_RESC0402_L
U$20: 4.7u; NORDIC_NRF_3_RESC0201_L
U$22: 32MHz; NORDIC_NRF_BT-XTAL_2016_N
U$31: NORDIC_NRF_4_NRF52840_QF; NORDIC_NRF_4_AQFN50P700X700X85_HS-74N
X1: 32.768kHz; NORDIC_NRF_1_XTAL_3215_N

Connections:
3V1: C35.1, U$31.P$AC5 (DEC3V3)
3V3: C3.1, C5.2, C12.1, C13.1, C15.1, C22.1, C26.1, C33.1, C36.1, IC2.E2 (VOUT_1), IC2.E3 (VOUT_2), IC3.C2 (VDD), IC4.3 (VDDIO), IC4.7 (VDD), IC4.10 (CSB), J2.1, Q2.2 (S), R3.1, R10.1, R11.1, R12.2, R13.2, R14.2, TP7.TP, U$31.P$A22 (VDD), U$31.P$AD14 (VDD), U$31.P$AD23 (VDD), U$31.P$B1 (VDD), U$31.P$W1 (VDD), U$31.P$Y2 (VDDH)
ALERT: U1.5 (!ALERT), U$31.P$J24 (P0.10/NFC2)
ANT: C29.1, U$5.1, U$31.P$H23 (ANT)
DEC1: C30.1, U$31.P$C1 (DEC1)
DEC3: C23.1, U$31.P$D23 (DEC3)
DEC4_6: C14.1, C20.1, C24.1, U$4.2, U$31.P$B5 (DEC4), U$31.P$E24 (DEC6)
DN: D4.1 (I/O1_1), J1.A7 (DN1), J1.B7 (DN2)
DP: D4.3 (I/O2_1), J1.A6 (DP1), J1.B6 (DP2)
D_N: D4.6 (I/O1_2), U$31.P$AD4 (D-)
D_P: D4.4 (I/O2_2), U$31.P$AD6 (D+)
EP: U1.9 (EP)
EPD_3V3: C17.1, C48.2, J3.15, J3.16, L4.2, Q2.3 (D)
EPD_BUSY: J3.9, U$31.P$AD12 (P0.17)
EPD_CS: J3.12, U$31.P$K2 (P0.05/AIN3)
EPD_DC: J3.11, U$31.P$AD10 (P0.15)
EPD_RST: J3.10, U$31.P$AC11 (P0.16)
GDR: J3.2, Q1.1 (G), R1.1
GND: C1.1, C2.1, C3.2, C4.1, C5.1, C6.1, C7.1, C8.1, C9.1, C10.1, C11.2, C12.2, C13.2, C14.2, C15.2, C17.2, C18.1, C19.1, C20.2, C21.2, C22.2, C23.2, C24.2, C25.2, C26.2, C27.2, C28.2, C29.2, C30.2, C31.2, C32.2, C33.2, C34.2, C35.2, C36.2, C37.1, C38.1, C39.1, C40.1, C41.1, C42.1, C43.1, C44.1, C45.1, C46.1, C47.1, C48.1, C49.2, D1.1 (K), D4.2 (GND), IC1.D2 (GND), IC2.B1 (VSEL), IC2.C1 (AGND), IC2.C2 (PGND_1), IC2.C3 (PGND_2), IC3.B1 (IN/TRIG), IC3.B3 (GND), IC4.8 (GNDIO), IC4.9 (GND), J1.A1_B12 (GND), J1.A12_B1 (GND), J1.SH1 (SHIELD), J1.SH2 (SHIELD), J1.SH3 (SHIELD), J1.SH4 (SHIELD), J2.3, J2.5, J3.8, J3.MP1, J3.MP2, R1.2, R4.2, R5.1, R8.1, R9.2, R15.2, SJ1.2, SW1.1, SW2.1, SW3.1, TP5.TP, TP13.TP, U1.1 (CTG), U1.4 (GND), U1.6 (QSTRT), U$20.2, U$22.2, U$22.4, U$31.P$74 (VSS_PAD), U$31.P$75 (VSS_PAD), U$31.P$76 (VSS_PAD), U$31.P$77 (VSS_PAD), U$31.P$78 (VSS_PAD), U$31.P$79 (VSS_PAD), U$31.P$80 (VSS_PAD), U$31.P$81 (VSS_PAD), U$31.P$82 (VSS_PAD), U$31.P$83 (VSS_PAD), U$31.P$84 (VSS_PAD), U$31.P$85 (VSS_PAD), U$31.P$86 (VSS_PAD), U$31.P$87 (VSS_PAD), U$31.P$88 (VSS_PAD), U$31.P$89 (VSS_PAD), U$31.P$90 (VSS_PAD), U$31.P$B7 (VSS), U$31.P$F23 (VSS_PA)
HAPTIC_EN: IC3.A1 (EN), U$31.P$U1 (P0.12)
IMU_INT1: IC4.5 (INT1), U$31.P$N1 (P0.08)
IMU_INT2: IC4.6 (INT2), U$31.P$P2 (P1.08)
LX1: IC2.B2 (SW1_1), IC2.B3 (SW1_2), L2.1
LX2: IC2.D2 (SW2_1), IC2.D3 (SW2_2), L2.2
MOSI: J3.14, U$31.P$B13 (P0.03/AIN1)
unnamed: C18.2, U$31.P$D2 (P0.00/XL1), X1.2
unnamed: C19.2, U$31.P$F2 (P0.01/XL2), X1.1
unnamed: U$4.1, U$8.2
unnamed: U$8.1, U$31.P$B3 (DCC)
unnamed: C25.1, U$31.P$N24 (DEC5)
unnamed: IC1.D1 (TS/MR), R5.2
unnamed: ANT1.1 (FEED), C31.1, C32.1, U$5.2
unnamed: C21.1, U$31.P$A18 (DEC2)
unnamed: IC2.D1 (SCL), R6.1
unnamed: IC2.E1 (SDA), R7.1
unnamed: C6.2, IC3.A2 (REG)
unnamed: J1.A5 (CC1), R8.2
unnamed: J1.B5 (CC2), R9.1
unnamed: Q1.2 (S), R2.1
unnamed: IC4.1 (SDO), R15.1
unnamed: C38.2, J3.4
unnamed: C39.2, J3.5
unnamed: R2.2, R4.1, SJ1.1
unnamed: C16.1, D1.2 (A), D2.1 (K)
unnamed: C16.2, D3.2 (A), L4.1, Q1.3 (D)
unnamed: C40.2, J3.17
unnamed: C41.2, J3.18
unnamed: C42.2, J3.19
unnamed: C43.2, J3.20
unnamed: C45.2, J3.22
unnamed: C47.2, J3.24
OUT+: IC3.A3 (OUT+), TP10.TP
OUT-: IC3.C3 (OUT-), TP11.TP
P0.04: U$31.P$J1 (P0.04/AIN2)
P0.09: U$31.P$L24 (P0.09/NFC1)
P0.13: C7.2, R12.1, SW1.2, U$31.P$AD8 (P0.13)
P0.14: C8.2, R13.1, SW2.2, U$31.P$AC9 (P0.14)
P0.19: U$31.P$AC15 (P0.19)
P0.20: U$31.P$AD16 (P0.20)
P0.21: U$31.P$AC17 (P0.21)
P0.22: U$31.P$AD18 (P0.22)
P0.23: U$31.P$AC19 (P0.23)
P0.24: U$31.P$AD20 (P0.24)
P0.25: U$31.P$AC21 (P0.25)
P0.26: U$31.P$G1 (P0.26)
P0.27: U$31.P$H2 (P0.27)
P0.28: U$31.P$B11 (P0.28/AIN4)
P0.29: U$31.P$A10 (P0.29/AIN5)
P0.30: U$31.P$B9 (P0.30/AIN6)
P0.31: U$31.P$A8 (P0.31/AIN7)
P1.01: Q2.1 (G), R3.2, U$31.P$Y23 (P1.01)
P1.02: C9.2, R14.1, SW3.2, U$31.P$W24 (P1.02)
P1.03: U$31.P$V23 (P1.03)
P1.04: U$31.P$U24 (P1.04)
P1.05: U$31.P$T23 (P1.05)
P1.06: U$31.P$R24 (P1.06)
P1.07: U$31.P$P23 (P1.07)
P1.09: U$31.P$R1 (P1.09)
P1.10: U$31.P$A20 (P1.10)
P1.11: U$31.P$B19 (P1.11)
P1.12: U$31.P$B17 (P1.12)
P1.13: U$31.P$A16 (P1.13)
P1.14: U$31.P$B15 (P1.14)
P1.15: U$31.P$A14 (P1.15)
PMIC_INT: IC1.A1 (!INT), U$31.P$T2 (P0.11)
PREVGH: C44.2, D3.1 (K), J3.21
PREVGL: C46.2, D2.2 (A), J3.23
RESE: J3.3
RESET: TP4.TP, U$31.P$AC13 (P0.18/RESET)
SCK: J3.13, U$31.P$A12 (P0.02/AIN0)
SCL: IC1.B1 (SCL), IC3.C1 (SCL), IC4.12 (SCX), R6.2, R10.2, TP6.TP, U1.7 (SCL), U$31.P$M2 (P0.07)
SDA: IC1.C1 (SDA), IC3.B2 (SDA), IC4.2 (SDX), R7.2, R11.2, TP8.TP, U1.8 (SDA), U$31.P$L1 (P0.06)
SWDCLK: J2.4, TP3.TP, U$31.P$AA24 (SWDCLK)
SWDIO: J2.2, TP2.TP, U$31.P$AC24 (SWDIO)
SWO: J2.6, TP1.TP, U$31.P$AD22 (P1.00)
VBAT: C2.2, C10.2, IC1.C2 (BAT), TP12.TP, U1.2 (CELL), U1.3 (VDD)
VBUS: C1.2, C4.2, C34.1, D4.5 (VBUS), IC1.A2 (IN), J1.A4_B9 (VBUS), J1.A9_B4 (VBUS), U$20.1, U$31.P$AD2 (VBUS)
VREG: C11.1, C37.2, C49.1, IC1.B2 (SYS), IC2.A1 (EN), IC2.A2 (VIN_1), IC2.A3 (VIN_2), TP9.TP
XC1: C28.1, U$22.1, U$31.P$B24 (XC1)
XC2: C27.1, U$22.3, U$31.P$A23 (XC2)

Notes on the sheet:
LiPo Charger
DC/DC
MCU
IMU
Fuel Gauge
E-Paper Display Connector
USB-C Connector & ESD
Haptic Driver
E-Paper Drive

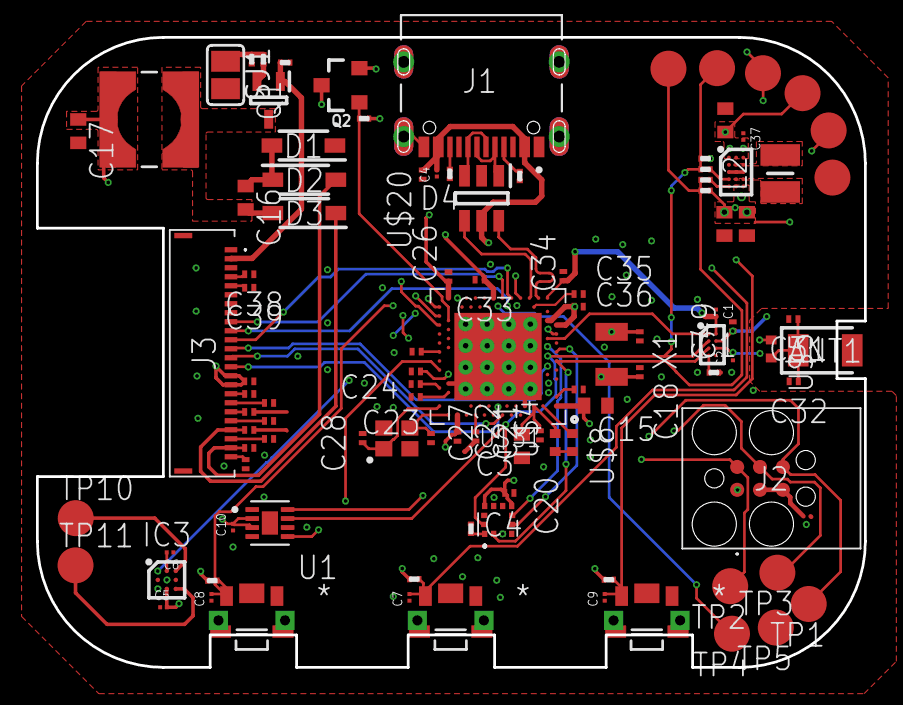
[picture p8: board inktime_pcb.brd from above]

Board: 4 copper layers, 46.0 x 35.0 mm, 105 parts (0 on the bottom side), 71 nets.

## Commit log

2026-04-10 added schematic and base PCB
    [inktime_pcb.brd, inktime_schematic.sch]
2026-04-21 final version
    [Inktime PCB v43.csv, PnP_Inktime PCB v43_front.csv, inktime_pcb.brd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]
2026-04-21 3d files
    [Display_3dModel.step, Vibrate_3dModel.step]
2026-04-21 added assembly image
2026-04-21 removed cable

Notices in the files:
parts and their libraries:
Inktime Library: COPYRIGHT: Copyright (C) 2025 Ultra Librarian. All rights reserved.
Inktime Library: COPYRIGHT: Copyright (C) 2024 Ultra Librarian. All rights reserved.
